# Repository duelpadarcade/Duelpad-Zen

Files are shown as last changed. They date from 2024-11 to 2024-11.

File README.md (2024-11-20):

## **Duelpad Zen**

Duelpad zen is a split-layout all-button controller, which is based on GP2040-CE projects. So it inherits the features, and is also added with something new.




## **Features**

- A navigating stick used with a humble UI,which can change the working status of the controller.
- Select from 13 input modes including X-Input, Nintendo Switch, Playstation 4/5, Xbox One, D-Input, and Keyboard
- Input latency average of 0.76ms in Xinput and 0.90ms for Playstation 5.
- Multiple SOCD cleaning modes - Up Priority (a.k.a. Stickless), Neutral, and Second Input Priority.
- Left and Right stick emulation via D-pad inputs as well as dedicated toggle switches.
- Dual direction via D-pad + LS/RS.
- Reversed input via a button.
- [Turbo and Turbo LED](https://gp2040-ce.info/add-ons/turbo) with selectable speed
- Per-button RGB LED support.
- PWM Player indicator LED support (XInput only).
- Multiple LED profiles support.
- Support for 128x64 monochrome I2C displays - SSD1306, SH1106, and SH1107 compatible.
- Custom startup splash screen and easy image upload via web configuration.
- Support for passive buzzer speaker (3v or 5v).
- [Built-in, embedded web configuration](https://gp2040-ce.info/web-configurator) - No download required!
- A bunch of RGB lights run by an extra MCU

## Support

We welcome anyone with ideas or issues to join us:

Official Website: www.duelpad.com

Discord Server:[DUELPAD](https://discord.gg/BXeWntUJ8B)

## Acknowledgements

This project is based on the excellent work of GP2040-CE team([Contributors to OpenStickCommunity/GP2040-CE · GitHub](https://github.com/OpenStickCommunity/GP2040-CE/graphs/contributors))

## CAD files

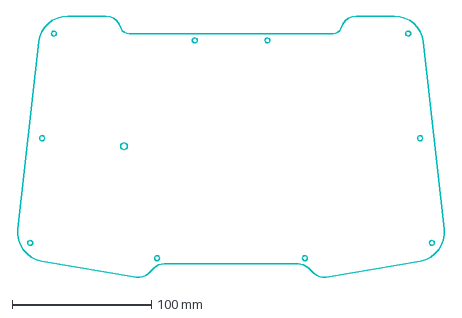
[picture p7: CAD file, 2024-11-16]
laser cut/Zen16-top4.dxf
308.3 x 187.8 mm

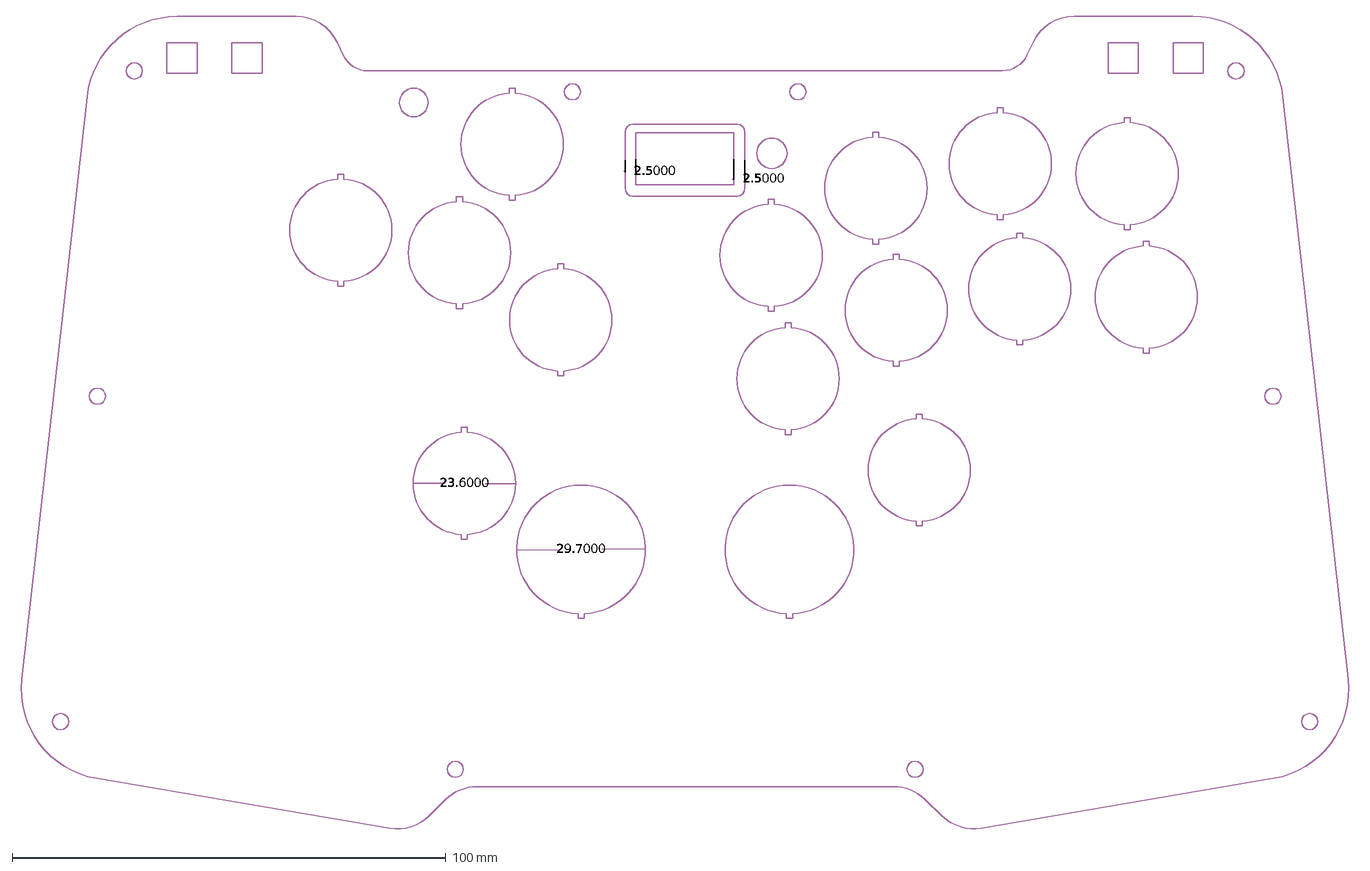
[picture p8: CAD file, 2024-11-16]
laser cut/Zen16-top1-balck.dxf
23.6000
29.7000
2.5000

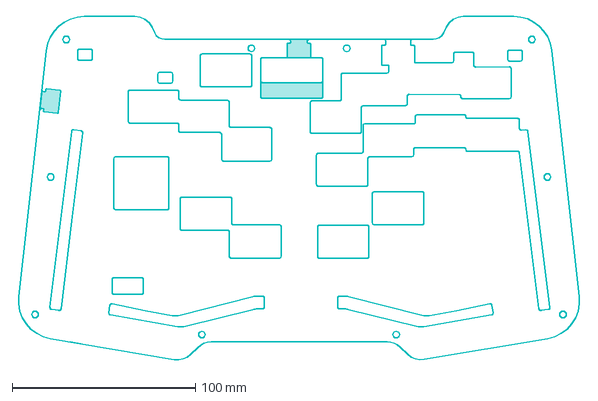
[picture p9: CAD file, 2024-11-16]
laser cut/Zen16-top3.dxf
308.3 x 187.8 mm

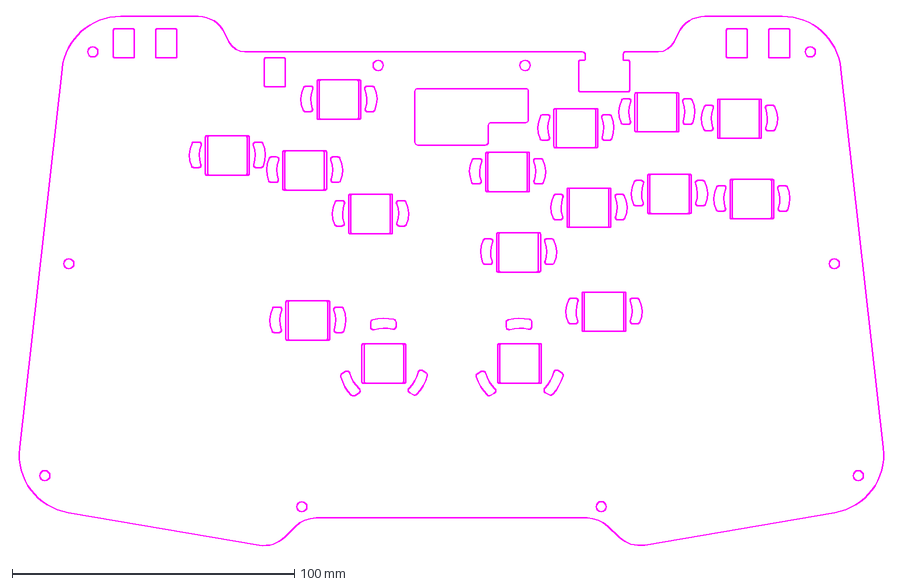
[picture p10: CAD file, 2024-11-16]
laser cut/Zen16-top2.dxf
308.3 x 187.8 mm

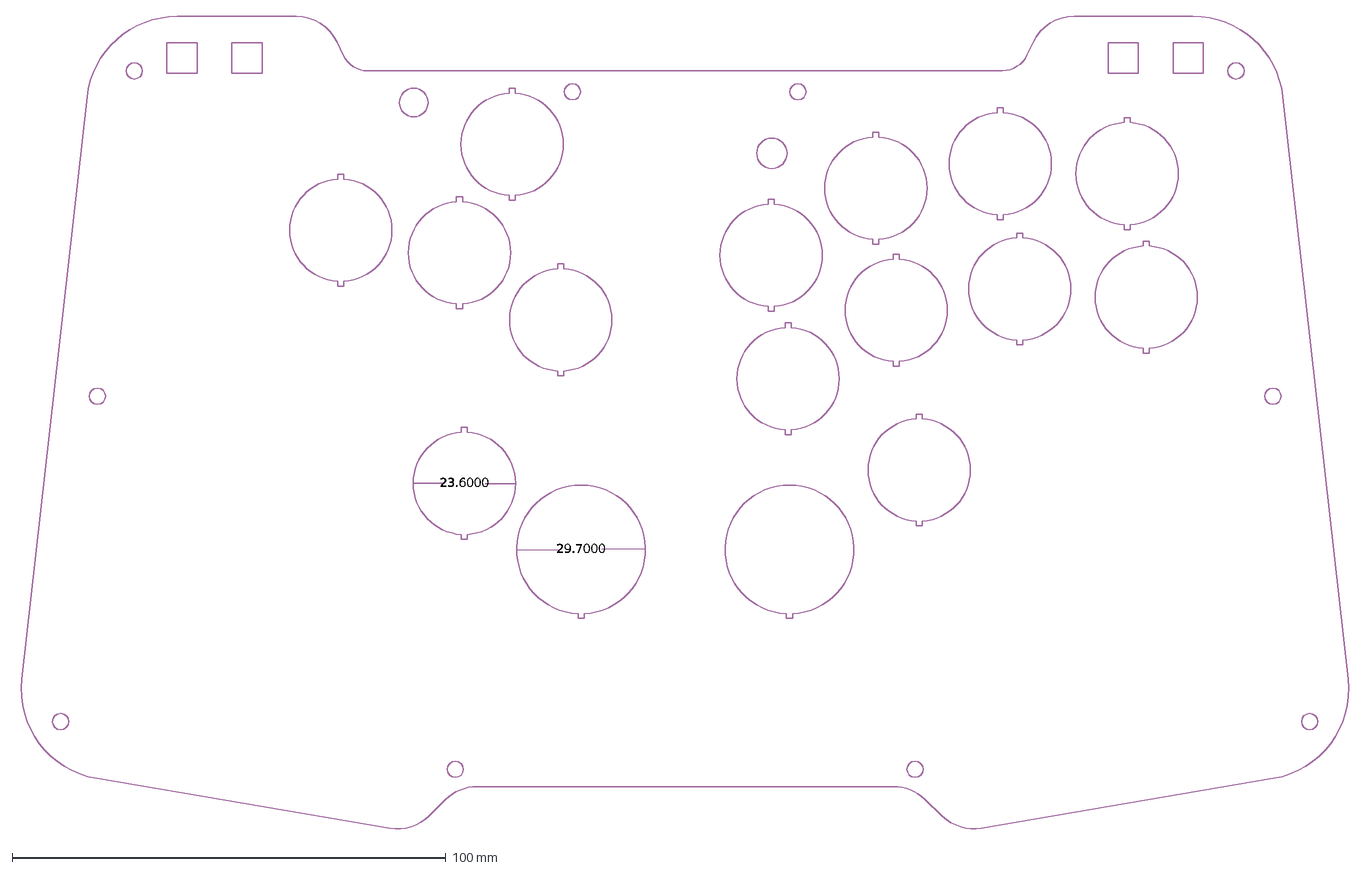
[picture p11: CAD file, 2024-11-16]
laser cut/Zen16-top1-crystal.dxf
23.6000
29.7000

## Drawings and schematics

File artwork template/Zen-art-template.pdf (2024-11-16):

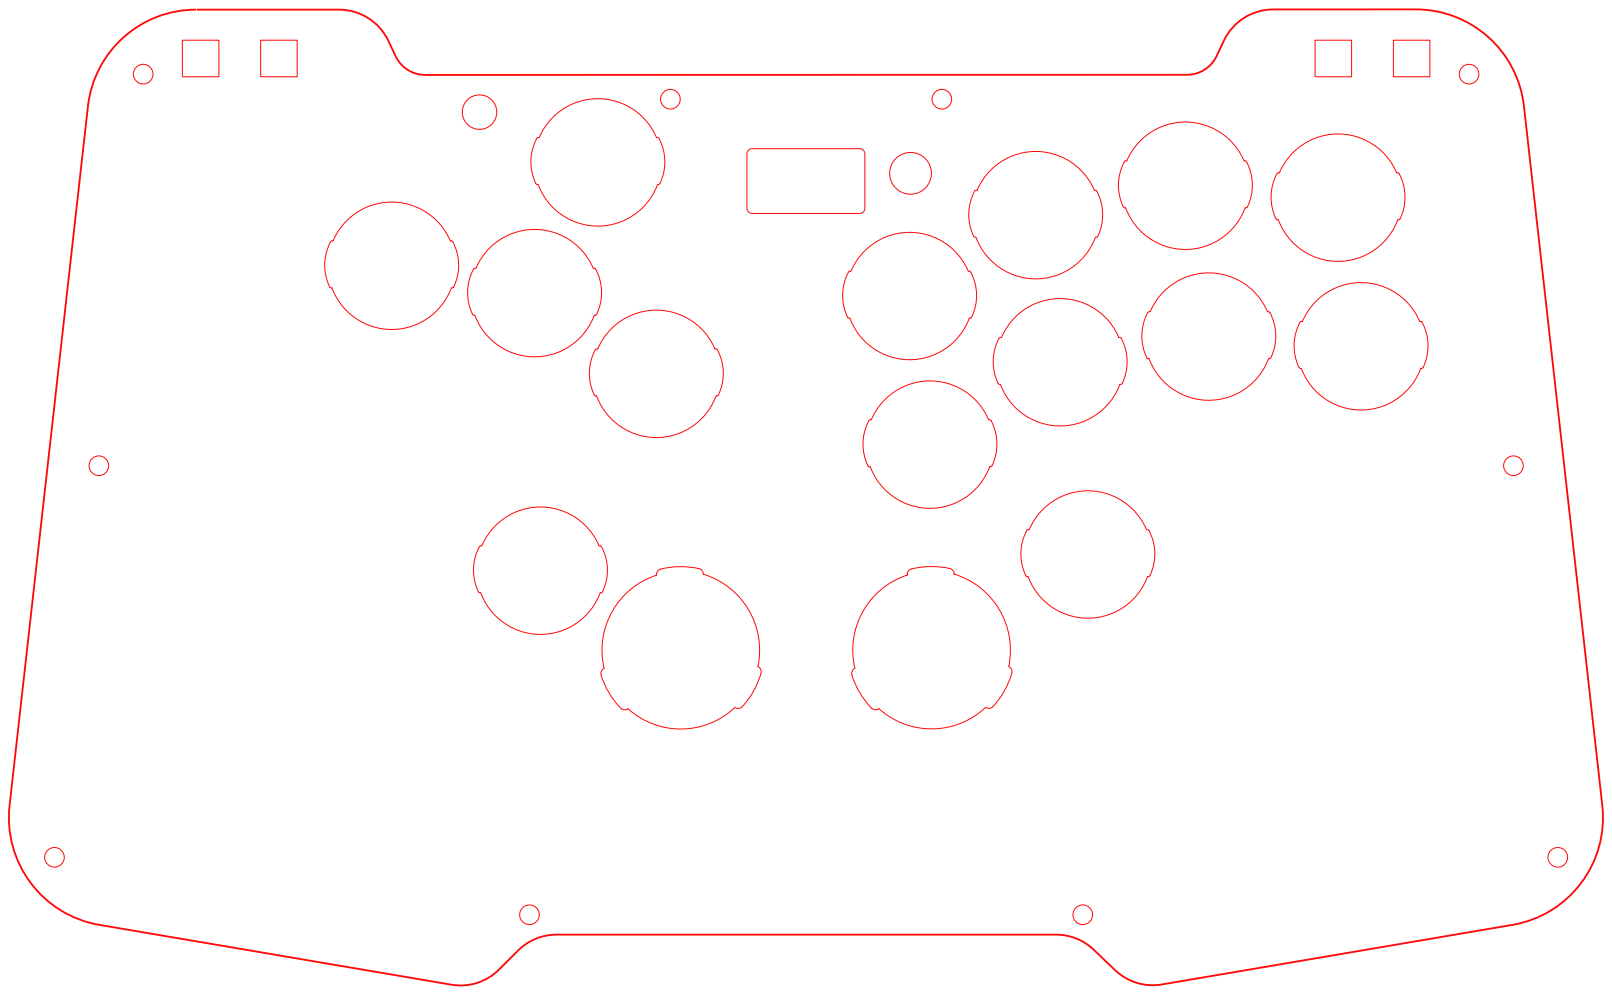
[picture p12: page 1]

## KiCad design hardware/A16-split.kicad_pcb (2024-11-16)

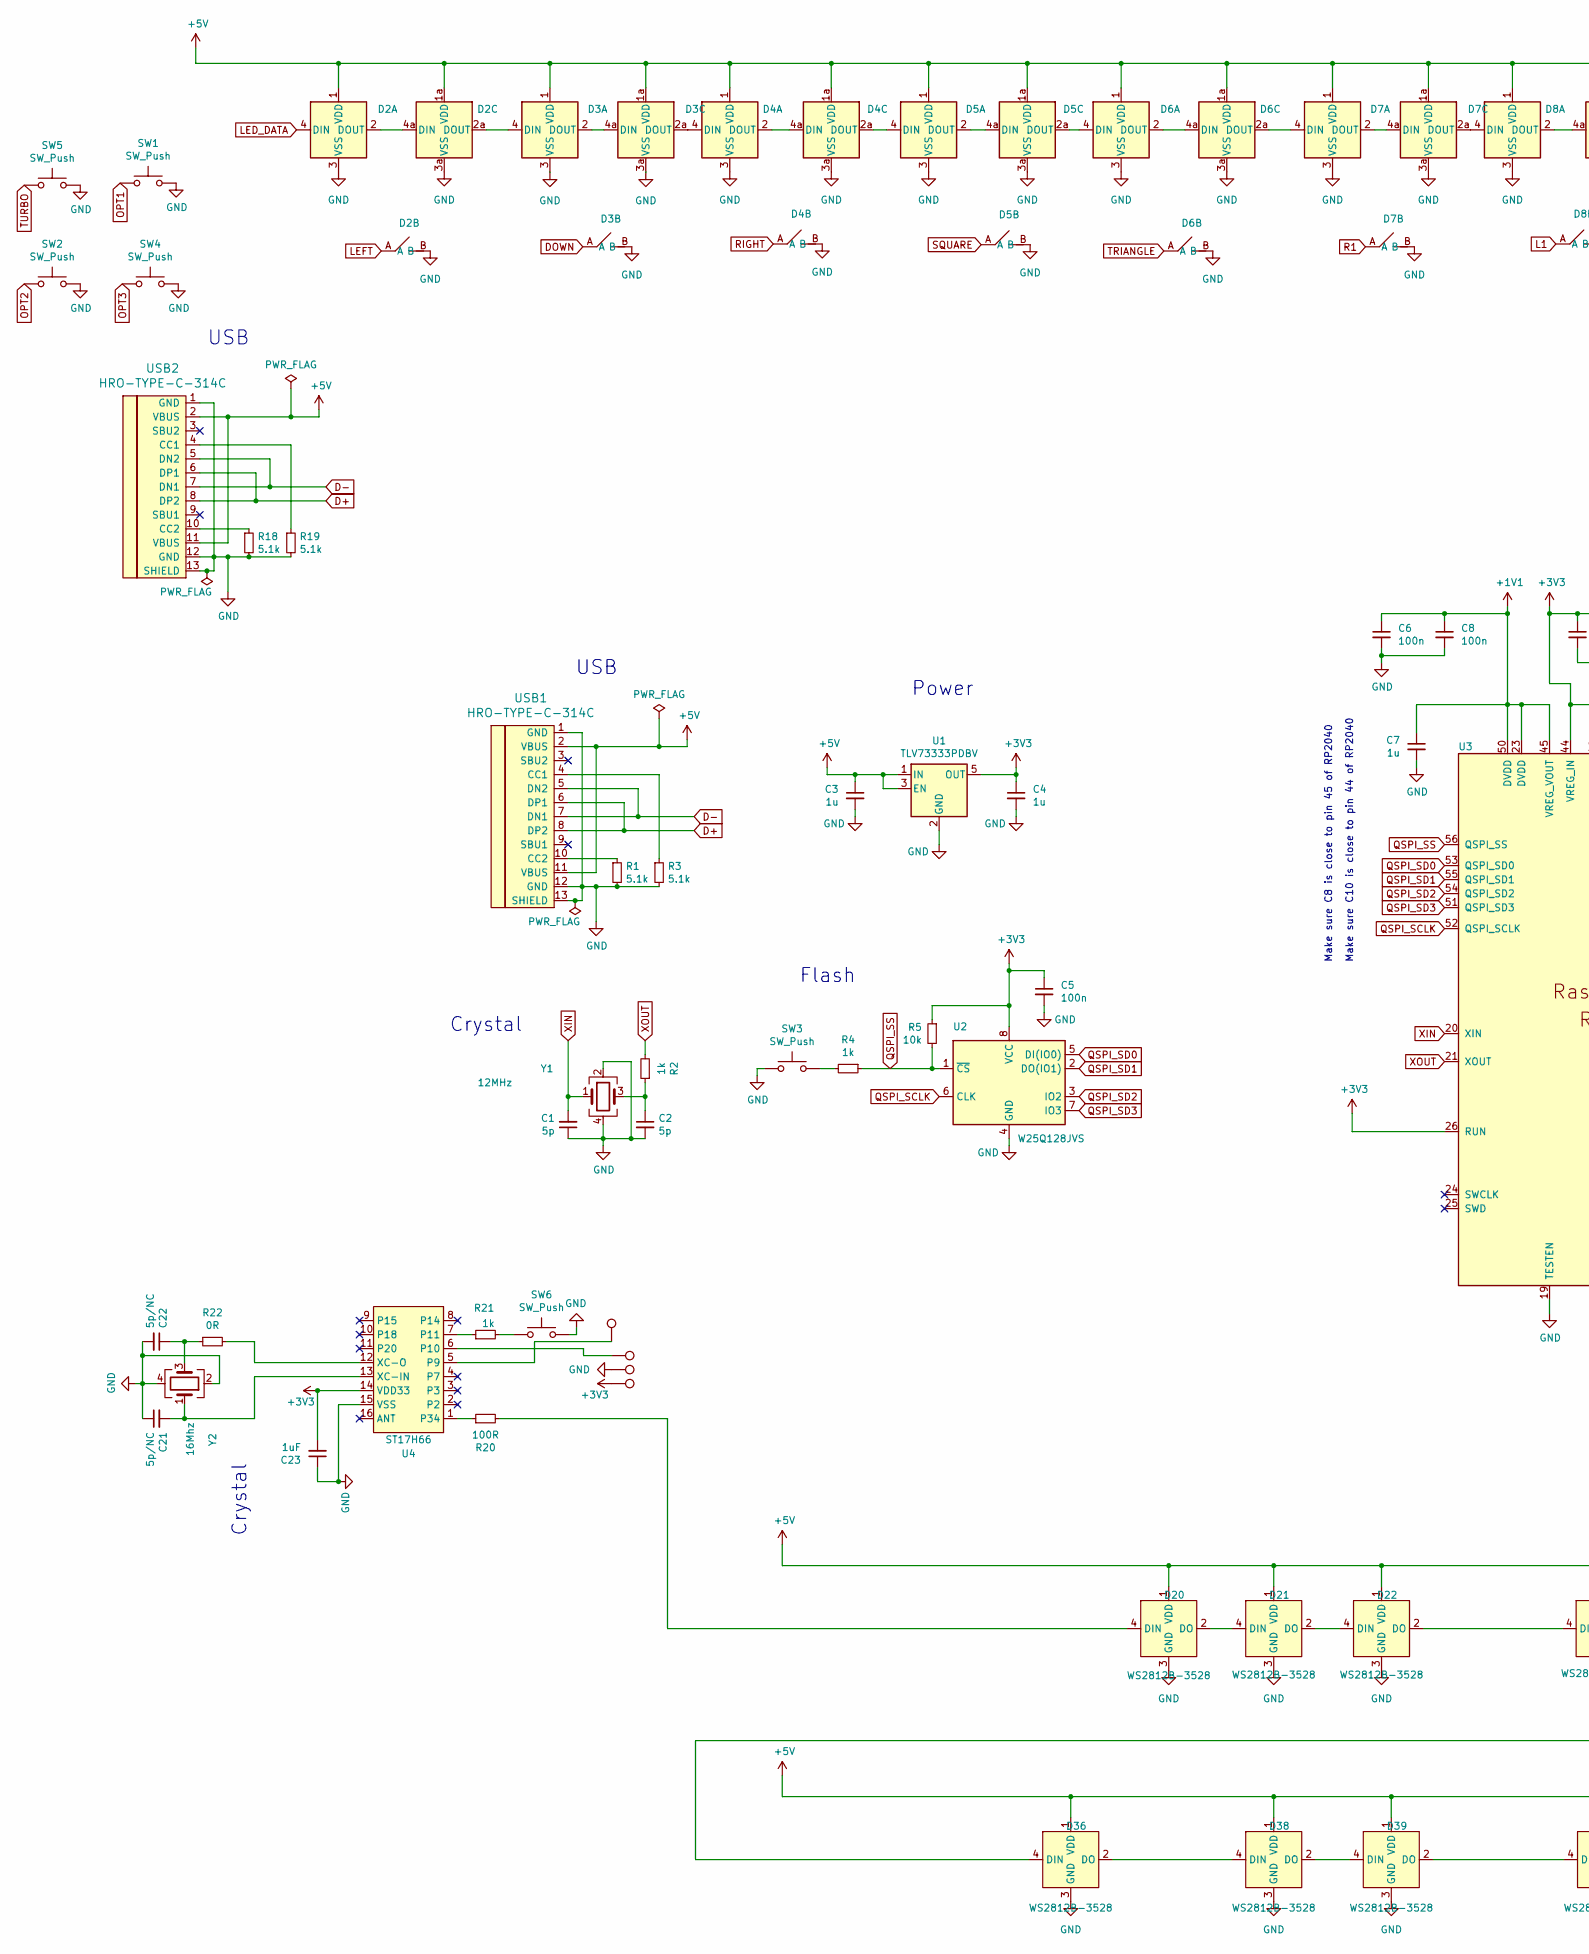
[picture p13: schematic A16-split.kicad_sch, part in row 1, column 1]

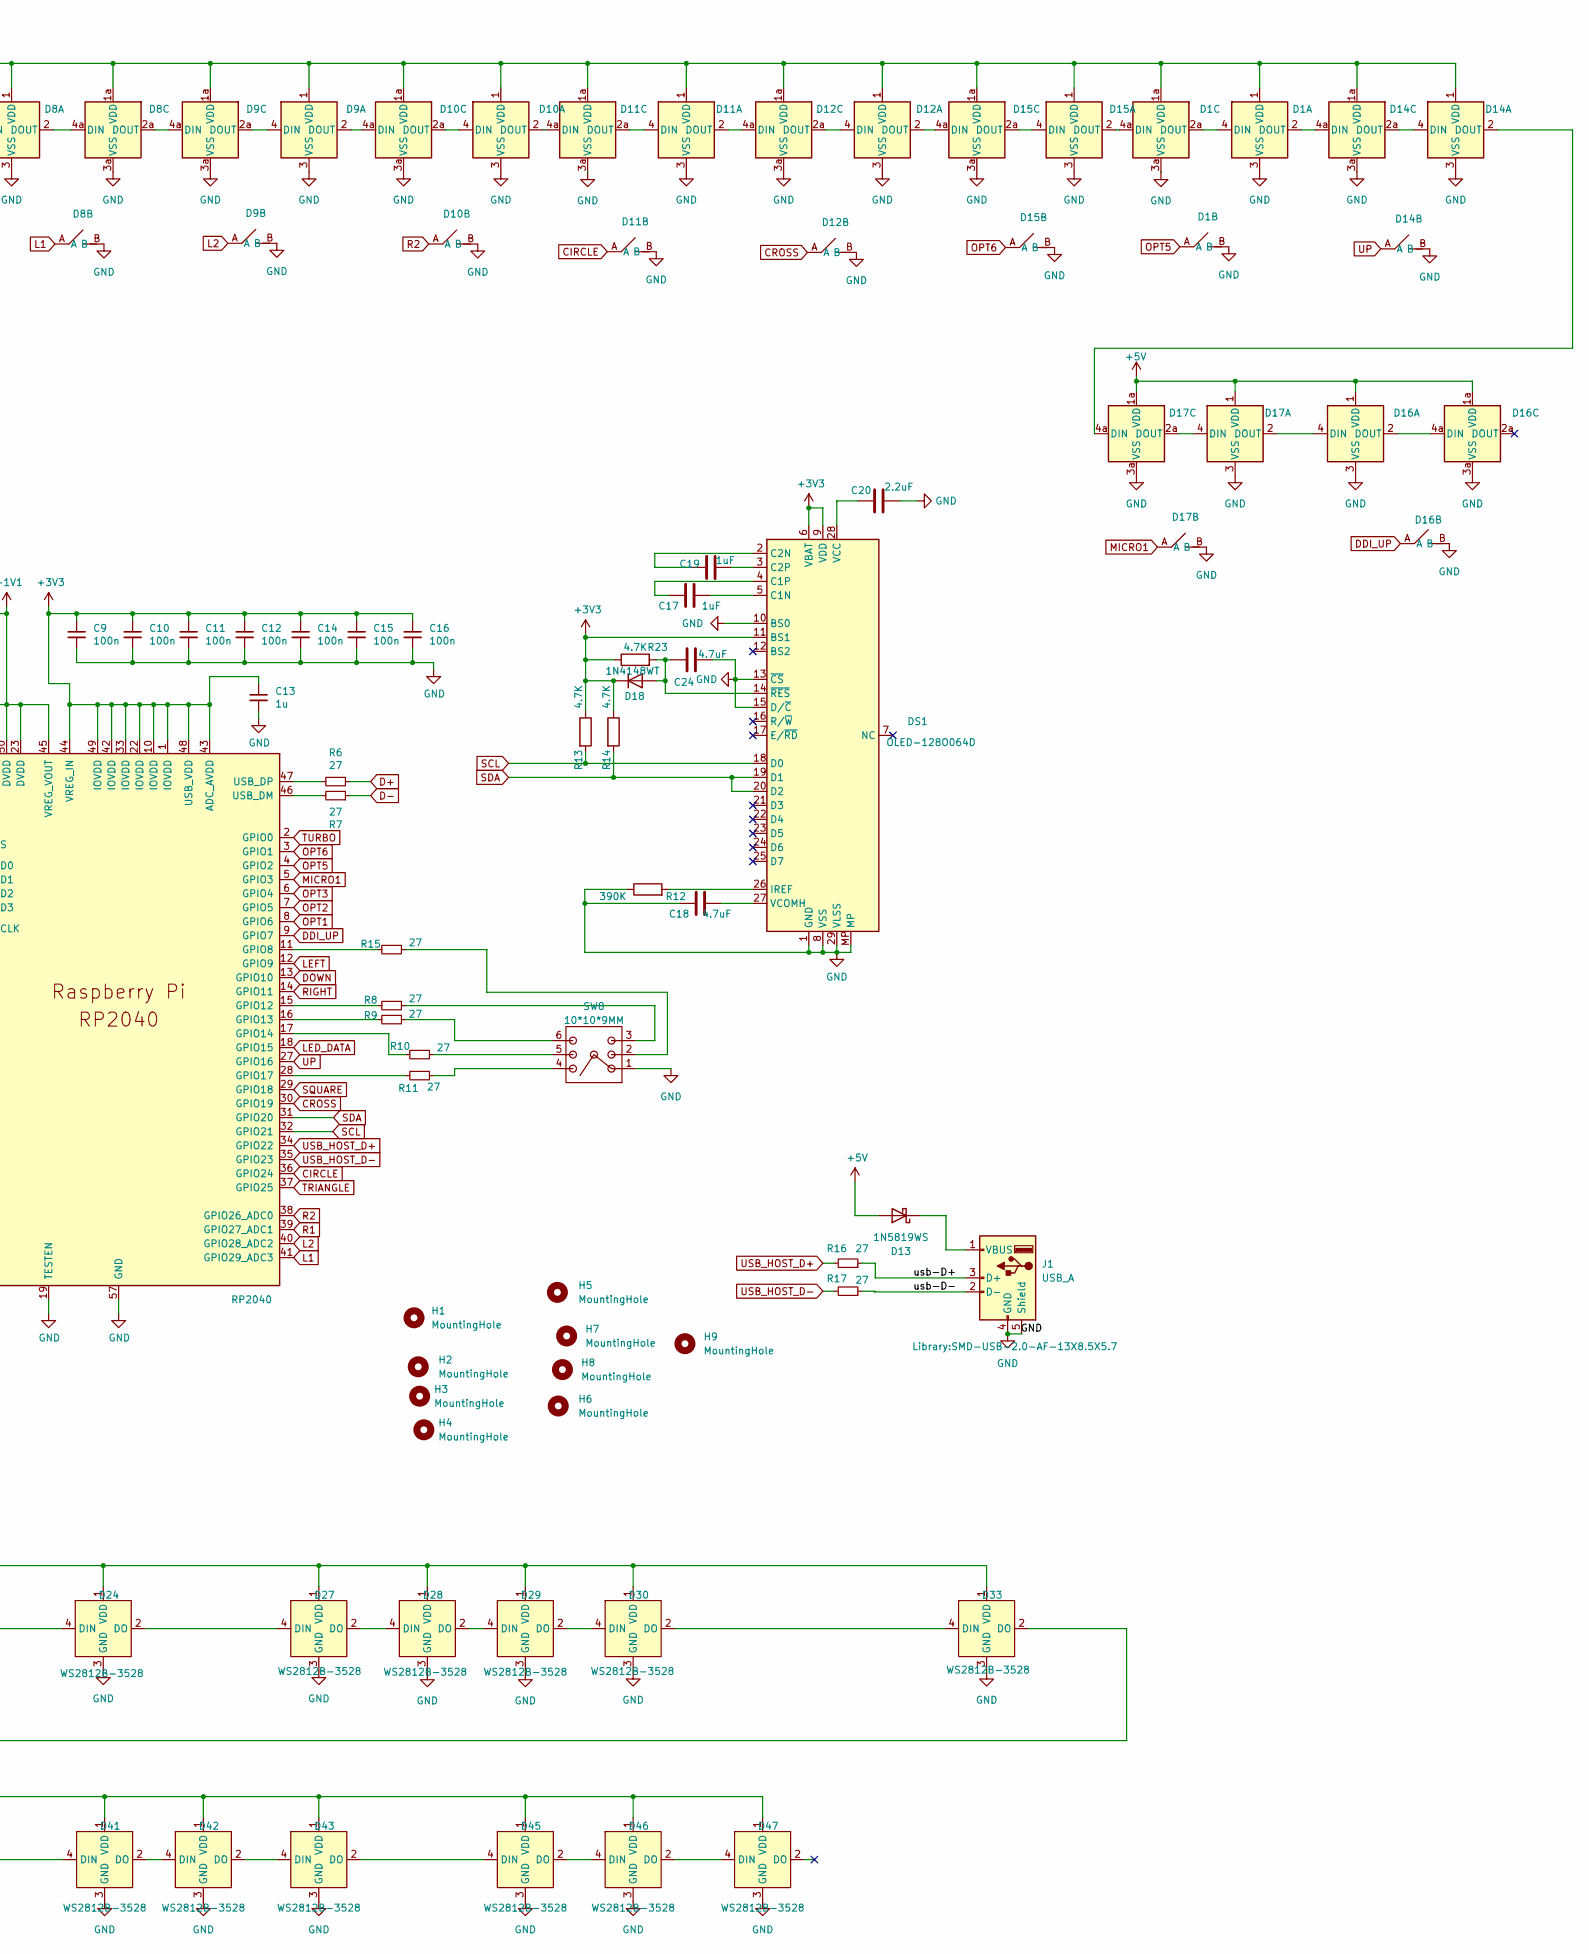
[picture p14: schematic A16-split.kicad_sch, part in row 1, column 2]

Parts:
C1, C2: 5p; C_0402_1005Metric; LCSC C1570
C3, C4, C7, C13: 1u; C_0402_1005Metric; LCSC C52923
C5, C6, C8, C9, C10, C11, C12, C14, C15, C16: 100n; C_0402_1005Metric; LCSC C1525
C17, C19: 1uF; C_0402_1005Metric
C18, C24: 4.7uF; C_0603_1608Metric
C20: 2.2uF; C_0603_1608Metric
C21, C22: 5p/NC; C_0402_1005Metric; LCSC C1570
C23: 1uF; C_0402_1005Metric; LCSC C52923
D1, D2, D3, D4, D5, D6, D7, D8, D9, D10, D11, D12, D14, D15, D16, D17: GATERON_KB_HOTSWAP_WS2812B; gateron_Kailh_PG1353_2LED-5.1MM
D13: 1N5819WS; D_SOD-323
D18: 1N4148WT; D_SOD-523
D20, D21, D22, D24, D27, D28, D29, D30, D33, D36, D38, D39, D41, D42, D43, D45, D46, D47: WS2812B-3528; SMD-LED-WS2812B-3528
DS1: OLED-128O064D; Flatbox_OLED_096-1
H1, H2, H3, H4, H5, H6, H7, H8, H9: MountingHole; MountingHole_3.15mm_M6
J1: USB_A; SMD-USB-2.0-AF-13X8.5X5.7
R1, R3, R18, R19: 5.1k; R_0402_1005Metric; LCSC C25905
R2, R4, R21: 1k; R_0402_1005Metric; LCSC C11702
R5: 10k; R_0402_1005Metric; LCSC C25744
R6, R7, R8, R9, R10, R11, R15, R16, R17: 27; R_0402_1005Metric; LCSC C138021
R12: 390K; R_0402_1005Metric
R13, R14, R23: 4.7K; R_0402_1005Metric
R20: 100R; R_0402_1005Metric; LCSC C11702
R22: 0R; R_0402_1005Metric; LCSC C11702
SW1, SW2, SW4, SW5: SW_Push; SW_Push_1P1T_NO_6x6mm_H5mm
SW3, SW6: SW_Push; SW_Push_1P1T_NO_6x6mm_H5mm; LCSC C271750
SW8: 10*10*9MM; TSX103G901-10x10
TP1, TP2, TP3, TP4: TestPoint; TestPoint_Pad_D1.5mm
U1: TLV73333PDBV; SOT-23-5; LCSC C134139
U2: W25Q128JVS; SOIC-8_5.23x5.23mm_P1.27mm; LCSC C97521
U3: RP2040; RP2040-QFN-56; LCSC C2040
U4: ST17H66; TSSOP-16_4.4x5mm_P0.65mm
USB1, USB2: HRO-TYPE-C-314C; HRO-TYPE-MC-314C-4P16; LCSC C165948
Y1: 12MHz; Crystal_SMD_3225-4Pin_3.2x2.5mm; LCSC C9002
Y2: 16Mhz; Crystal_SMD_3225-4Pin_3.2x2.5mm; LCSC C9002

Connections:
+1V1: C6.1, C7.1, C8.1, U3.23 (DVDD), U3.45 (VREG_VOUT), U3.50 (DVDD)
+3V3: C4.1, C5.1, C9.1, C10.1, C11.1, C12.1, C13.1, C14.1, C15.1, C16.1, C23.2, D18.1 (K), DS1.6 (VBAT), DS1.9 (VDD), DS1.11 (BS1), R5.1, R13.1, R14.1, R23.1, TP4.1, U1.5 (OUT), U2.8 (VCC), U3.1 (IOVDD), U3.10 (IOVDD), U3.22 (IOVDD), U3.26 (RUN), U3.33 (IOVDD), U3.42 (IOVDD), U3.43 (ADC_AVDD), U3.44 (VREG_IN), U3.48 (USB_VDD), U3.49 (IOVDD), U4.14 (VDD33)
+5V: C3.1, D1.1 (VDD), D1.1a (VDD), D2.1 (VDD), D2.1a (VDD), D3.1 (VDD), D3.1a (VDD), D4.1 (VDD), D4.1a (VDD), D5.1 (VDD), D5.1a (VDD), D6.1 (VDD), D6.1a (VDD), D7.1 (VDD), D7.1a (VDD), D8.1 (VDD), D8.1a (VDD), D9.1 (VDD), D9.1a (VDD), D10.1 (VDD), D10.1a (VDD), D11.1 (VDD), D11.1a (VDD), D12.1 (VDD), D12.1a (VDD), D13.2 (A), D14.1 (VDD), D14.1a (VDD), D15.1 (VDD), D15.1a (VDD), D16.1 (VDD), D16.1a (VDD), D17.1 (VDD), D17.1a (VDD), D20.1 (VDD), D21.1 (VDD), D22.1 (VDD), D24.1 (VDD), D27.1 (VDD), D28.1 (VDD), D29.1 (VDD), D30.1 (VDD), D33.1 (VDD), D36.1 (VDD), D38.1 (VDD), D39.1 (VDD), D41.1 (VDD), D42.1 (VDD), D43.1 (VDD), D45.1 (VDD), D46.1 (VDD), D47.1 (VDD), U1.1 (IN), U1.3 (EN), USB1.2 (VBUS), USB1.11 (VBUS), USB2.2 (VBUS), USB2.11 (VBUS)
/usb-D+: J1.3 (D+), R16.1
/usb-D-: J1.2 (D-), R17.1
CIRCLE: D11.A, U3.36 (GPIO24)
CROSS: D12.A, U3.30 (GPIO19)
D+: R6.1, USB1.6 (DP1), USB1.8 (DP2), USB2.6 (DP1), USB2.8 (DP2)
D-: R7.1, USB1.5 (DN2), USB1.7 (DN1), USB2.5 (DN2), USB2.7 (DN1)
DDI_UP: D16.A, U3.9 (GPIO7)
DOWN: D3.A, U3.13 (GPIO10)
GND: C1.1, C2.2, C3.2, C4.2, C5.2, C6.2, C7.2, C8.2, C9.2, C10.2, C11.2, C12.2, C13.2, C14.2, C15.2, C16.2, C18.1, C20.2, C21.1, C22.2, C23.1, C24.2, D1.3 (VSS), D1.3a (VSS), D1.B, D2.3 (VSS), D2.3a (VSS), D2.B, D3.3 (VSS), D3.3a (VSS), D3.B, D4.3 (VSS), D4.3a (VSS), D4.B, D5.3 (VSS), D5.3a (VSS), D5.B, D6.3 (VSS), D6.3a (VSS), D6.B, D7.3 (VSS), D7.3a (VSS), D7.B, D8.3 (VSS), D8.3a (VSS), D8.B, D9.3 (VSS), D9.3a (VSS), D9.B, D10.3 (VSS), D10.3a (VSS), D10.B, D11.3 (VSS), D11.3a (VSS), D11.B, D12.3 (VSS), D12.3a (VSS), D12.B, D14.3 (VSS), D14.3a (VSS), D14.B, D15.3 (VSS), D15.3a (VSS), D15.B, D16.3 (VSS), D16.3a (VSS), D16.B, D17.3 (VSS), D17.3a (VSS), D17.B, D20.3 (GND), D21.3 (GND), D22.3 (GND), D24.3 (GND), D27.3 (GND), D28.3 (GND), D29.3 (GND), D30.3 (GND), D33.3 (GND), D36.3 (GND), D38.3 (GND), D39.3 (GND), D41.3 (GND), D42.3 (GND), D43.3 (GND), D45.3 (GND), D46.3 (GND), D47.3 (GND), DS1.1 (GND), DS1.8 (VSS), DS1.10 (BS0), DS1.13 (~CS), DS1.15 (D/~C), DS1.29 (VLSS), DS1.30 (GND), DS1.MP, J1.4 (GND), J1.5 (Shield), R1.2, R3.2, R12.1, R18.2, R19.2, SW1.2, SW2.2, SW3.1, SW4.2, SW5.2, SW6.2, SW8.1, TP3.1, U1.2 (GND), U2.4 (GND), U3.19 (TESTEN), U3.57 (GND), U4.15 (VSS), USB1.1 (GND), USB1.12 (GND), USB1.13 (SHIELD), USB2.1 (GND), USB2.12 (GND), USB2.13 (SHIELD), Y1.2, Y1.4, Y2.2, Y2.4
L1: D8.A, U3.41 (GPIO29_ADC3)
L2: D9.A, U3.40 (GPIO28_ADC2)
LED_DATA: D2.4 (DIN), U3.18 (GPIO15)
LEFT: D2.A, U3.12 (GPIO9)
MICRO1: D17.A, U3.5 (GPIO3)
unnamed: C2.1, R2.1, Y1.3
unnamed: C22.1, R22.1, Y2.3
unnamed: D1.2a (DOUT), D1.4 (DIN)
unnamed: D2.2 (DOUT), D2.4a (DIN)
unnamed: D2.2a (DOUT), D3.4 (DIN)
unnamed: D3.2 (DOUT), D3.4a (DIN)
unnamed: D3.2a (DOUT), D4.4 (DIN)
unnamed: D4.2 (DOUT), D4.4a (DIN)
unnamed: D4.2a (DOUT), D5.4 (DIN)
unnamed: D5.2 (DOUT), D5.4a (DIN)
unnamed: D5.2a (DOUT), D6.4 (DIN)
unnamed: D6.2 (DOUT), D6.4a (DIN)
unnamed: D6.2a (DOUT), D7.4 (DIN)
unnamed: D7.2 (DOUT), D7.4a (DIN)
unnamed: D7.2a (DOUT), D8.4 (DIN)
unnamed: D8.2 (DOUT), D8.4a (DIN)
unnamed: D8.2a (DOUT), D9.4a (DIN)
unnamed: D9.2a (DOUT), D9.4 (DIN)
unnamed: D10.2a (DOUT), D10.4 (DIN)
unnamed: D10.2 (DOUT), D11.4a (DIN)
unnamed: D9.2 (DOUT), D10.4a (DIN)
unnamed: D11.2a (DOUT), D11.4 (DIN)
unnamed: D11.2 (DOUT), D12.4a (DIN)
unnamed: D12.2a (DOUT), D12.4 (DIN)
unnamed: D12.2 (DOUT), D15.4a (DIN)
unnamed: D13.1 (K), J1.1 (VBUS)
unnamed: D14.2a (DOUT), D14.4 (DIN)
unnamed: D14.2 (DOUT), D17.4a (DIN)
unnamed: D1.2 (DOUT), D14.4a (DIN)
unnamed: D15.2a (DOUT), D15.4 (DIN)
unnamed: D1.4a (DIN), D15.2 (DOUT)
unnamed: D16.4 (DIN), D17.2 (DOUT)
unnamed: D16.2 (DOUT), D16.4a (DIN)
unnamed: D17.2a (DOUT), D17.4 (DIN)
unnamed: C24.1, D18.2 (A), DS1.14 (~RES), R23.2
unnamed: D20.4 (DIN), R20.2
unnamed: D20.2 (DO), D21.4 (DIN)
unnamed: D21.2 (DO), D22.4 (DIN)
unnamed: D22.2 (DO), D24.4 (DIN)
unnamed: D24.2 (DO), D27.4 (DIN)
unnamed: D27.2 (DO), D28.4 (DIN)
unnamed: D28.2 (DO), D29.4 (DIN)
unnamed: D29.2 (DO), D30.4 (DIN)
unnamed: D30.2 (DO), D33.4 (DIN)
unnamed: D33.2 (DO), D36.4 (DIN)
unnamed: D36.2 (DO), D38.4 (DIN)
unnamed: D38.2 (DO), D39.4 (DIN)
unnamed: D39.2 (DO), D41.4 (DIN)
unnamed: D41.2 (DO), D42.4 (DIN)
unnamed: D42.2 (DO), D43.4 (DIN)
unnamed: D43.2 (DO), D45.4 (DIN)
unnamed: D45.2 (DO), D46.4 (DIN)
unnamed: D46.2 (DO), D47.4 (DIN)
unnamed: C17.2, DS1.5 (C1N)
unnamed: C17.1, DS1.4 (C1P)
unnamed: C19.1, DS1.2 (C2N)
unnamed: C19.2, DS1.3 (C2P)
unnamed: DS1.26 (IREF), R12.2
unnamed: C20.1, DS1.28 (VCC)
unnamed: C18.2, DS1.27 (VCOMH)
unnamed: R4.2, SW3.2
unnamed: R8.1, SW8.3
unnamed: R9.1, SW8.6
unnamed: R10.1, SW8.5
unnamed: R11.1, SW8.4
unnamed: R15.1, SW8.2
unnamed: R21.2, SW6.1
unnamed: R15.2, U3.11 (GPIO8)
unnamed: R8.2, U3.15 (GPIO12)
unnamed: R9.2, U3.16 (GPIO13)
unnamed: R10.2, U3.17 (GPIO14)
unnamed: R11.2, U3.28 (GPIO17)
unnamed: R7.2, U3.46 (USB_DM)
unnamed: R6.2, U3.47 (USB_DP)
unnamed: TP1.1, U4.5 (P9)
unnamed: TP2.1, U4.6 (P10)
unnamed: R21.1, U4.7 (P11)
unnamed: R20.1, U4.1 (P34)
unnamed: C21.2, U4.13 (XC-IN), Y2.1
unnamed: R22.2, U4.12 (XC-O)
unnamed: R3.1, USB1.4 (CC1)
unnamed: R1.1, USB1.10 (CC2)
unnamed: R19.1, USB2.4 (CC1)
unnamed: R18.1, USB2.10 (CC2)
OPT1: SW1.1, U3.8 (GPIO6)
OPT2: SW2.1, U3.7 (GPIO5)
OPT3: SW4.1, U3.6 (GPIO4)
OPT5: D1.A, U3.4 (GPIO2)
OPT6: D15.A, U3.3 (GPIO1)
QSPI_SCLK: U2.6 (CLK), U3.52 (QSPI_SCLK)
QSPI_SD0: U2.5 (DI(IO0)), U3.53 (QSPI_SD0)
QSPI_SD1: U2.2 (DO(IO1)), U3.55 (QSPI_SD1)
QSPI_SD2: U2.3 (IO2), U3.54 (QSPI_SD2)
QSPI_SD3: U2.7 (IO3), U3.51 (QSPI_SD3)
QSPI_SS: R4.1, R5.2, U2.1 (~CS), U3.56 (QSPI_SS)
R1: D7.A, U3.39 (GPIO27_ADC1)
R2: D10.A, U3.38 (GPIO26_ADC0)
RIGHT: D4.A, U3.14 (GPIO11)
SCL: DS1.18 (D0), R13.2, U3.32 (GPIO21)
SDA: DS1.19 (D1), DS1.20 (D2), R14.2, U3.31 (GPIO20)
SQUARE: D5.A, U3.29 (GPIO18)
TRIANGLE: D6.A, U3.37 (GPIO25)
TURBO: SW5.1, U3.2 (GPIO0)
UP: D14.A, U3.27 (GPIO16)
USB_HOST_D+: R16.2, U3.34 (GPIO22)
USB_HOST_D-: R17.2, U3.35 (GPIO23)
XIN: C1.2, U3.20 (XIN), Y1.1
XOUT: R2.2, U3.21 (XOUT)

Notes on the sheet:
USB
Make sure C10 is close to pin 44 of RP2040
Crystal
Flash
Power
Make sure C8 is close to pin 45 of RP2040

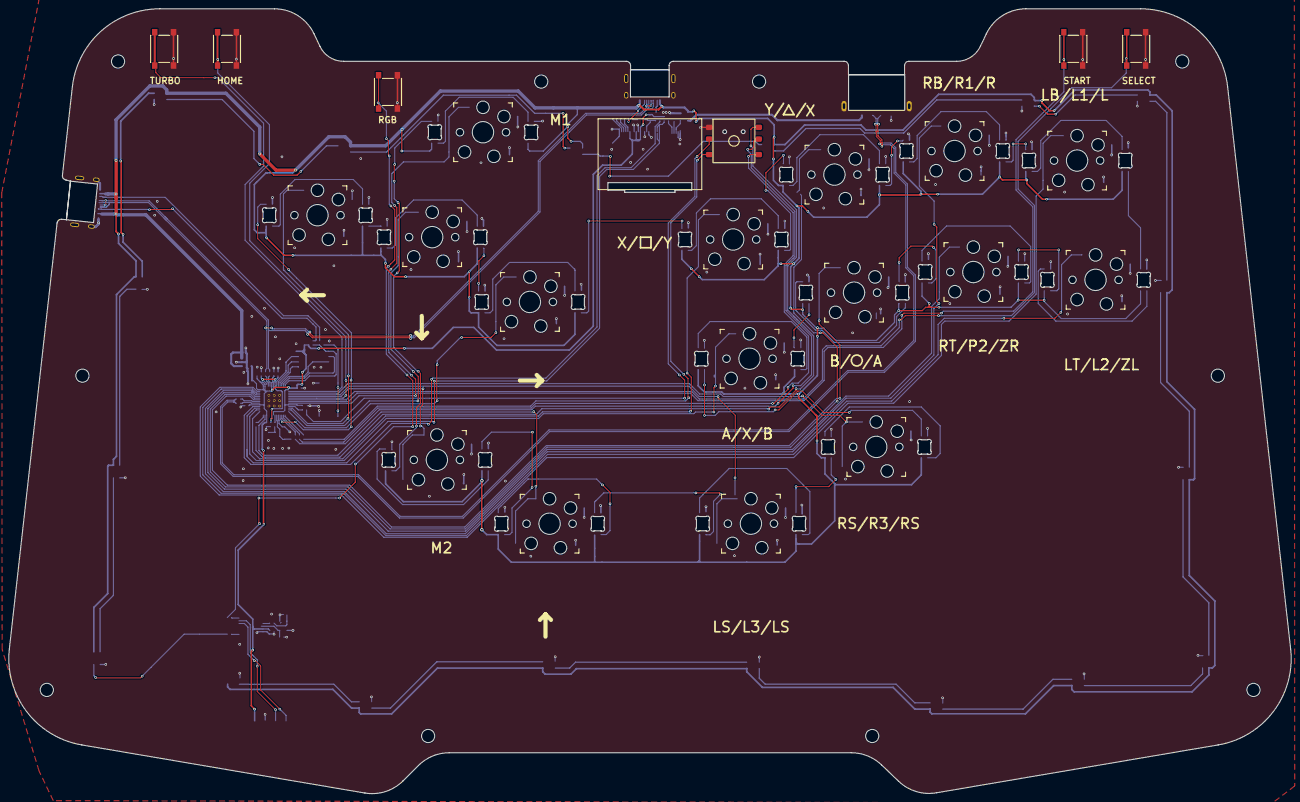
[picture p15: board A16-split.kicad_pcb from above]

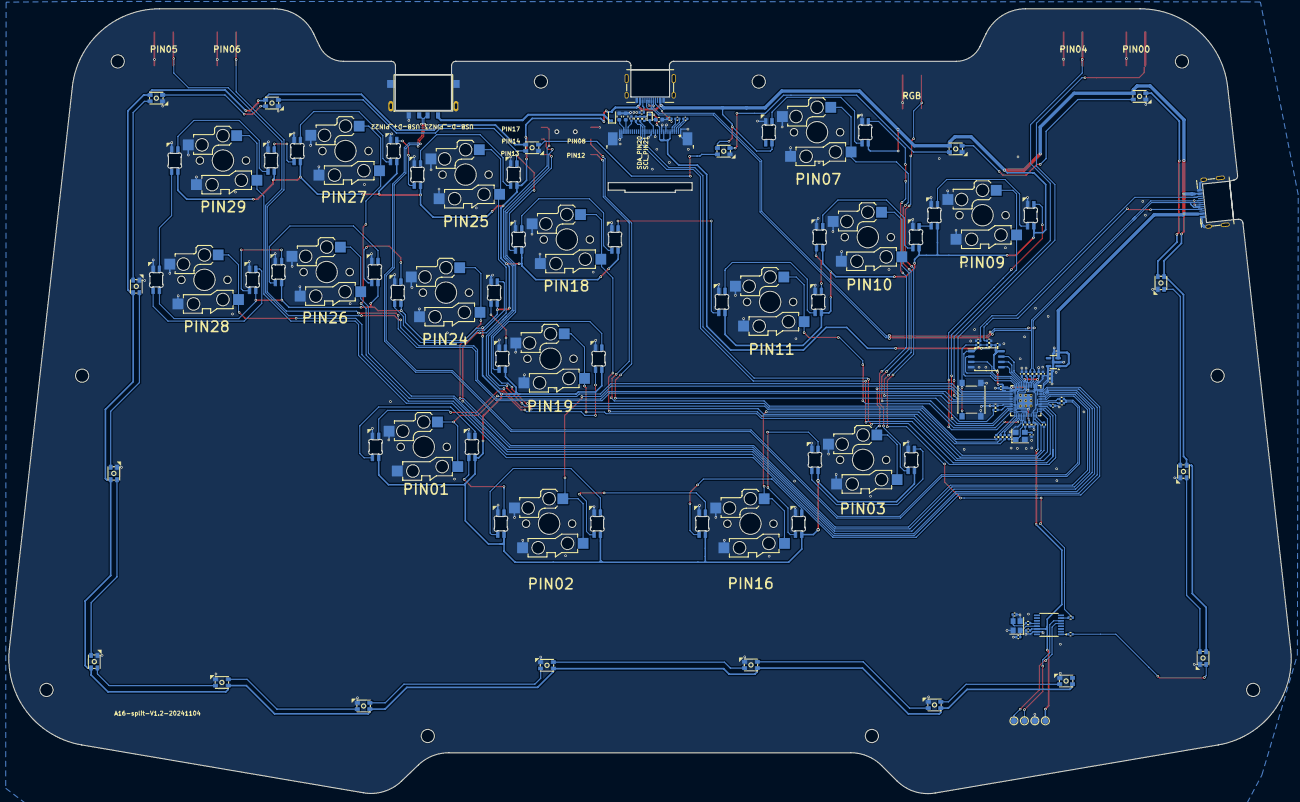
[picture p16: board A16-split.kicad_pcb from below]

Board: 2 copper layers, 306.1 x 187.3 mm, 114 parts (81 on the bottom side), 125 nets.

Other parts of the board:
H9#2: MountingHole; MountingHole_3.15mm_M6

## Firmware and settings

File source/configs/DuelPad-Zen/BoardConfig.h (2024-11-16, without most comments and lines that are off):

#define EPIG_A16_CONFIG_H_
#include "enums.pb.h"
#include "class/hid/hid.h"
#define BOARD_CONFIG_LABEL "DuelPad-Zen"
#define GPIO_PIN_16 GpioAction::BUTTON_PRESS_UP     // UP     | UP     | UP      | UP       | UP     | UP     |
#define GPIO_PIN_10 GpioAction::BUTTON_PRESS_DOWN   // DOWN   | DOWN   | DOWN    | DOWN     | DOWN   | DOWN   |
#define GPIO_PIN_11 GpioAction::BUTTON_PRESS_RIGHT  // RIGHT  | RIGHT  | RIGHT   | RIGHT    | RIGHT  | RIGHT  |
#define GPIO_PIN_09 GpioAction::BUTTON_PRESS_LEFT   // LEFT   | LEFT   | LEFT    | LEFT     | LEFT   | LEFT   |
#define GPIO_PIN_19 GpioAction::BUTTON_PRESS_B1     // B1     | A      | B       | Cross    | 2      | K1     |
#define GPIO_PIN_24 GpioAction::BUTTON_PRESS_B2     // B2     | B      | A       | Circle   | 3      | K2     |
#define GPIO_PIN_26 GpioAction::BUTTON_PRESS_R2     // R2     | RT     | ZR      | R2       | 8      | K3     |
#define GPIO_PIN_28 GpioAction::BUTTON_PRESS_L2     // L2     | LT     | ZL      | L2       | 7      | K4     |
#define GPIO_PIN_18 GpioAction::BUTTON_PRESS_B3     // B3     | X      | Y       | Square   | 1      | P1     |
#define GPIO_PIN_25 GpioAction::BUTTON_PRESS_B4     // B4     | Y      | X       | Triangle | 4      | P2     |
#define GPIO_PIN_27 GpioAction::BUTTON_PRESS_R1     // R1     | RB     | R       | R1       | 6      | P3     |
#define GPIO_PIN_29 GpioAction::BUTTON_PRESS_L1     // L1     | LB     | L       | L1       | 5      | P4     |
#define GPIO_PIN_05 GpioAction::BUTTON_PRESS_S1     // S1     | Back   | Minus   | Select   | 9      | Coin   |
#define GPIO_PIN_06 GpioAction::BUTTON_PRESS_S2     // S2     | Start  | Plus    | Start    | 10     | Start  |
#define GPIO_PIN_02 GpioAction::BUTTON_PRESS_L3     // L3     | LS     | LS      | L3       | 11     | LS     |
#define GPIO_PIN_01 GpioAction::BUTTON_PRESS_R3     // R3     | RS     | RS      | R3       | 12     | RS     |
#define GPIO_PIN_04 GpioAction::BUTTON_PRESS_A1     // A1     | Guide  | Home    | PS       | 13     | ~      |
#define GPIO_PIN_13 GpioAction::BUTTON_PRESS_E1     //
#define GPIO_PIN_17 GpioAction::BUTTON_PRESS_E2     //
#define GPIO_PIN_14 GpioAction::BUTTON_PRESS_E3     //press
#define GPIO_PIN_08 GpioAction::BUTTON_PRESS_E4     //left
#define GPIO_PIN_12 GpioAction::BUTTON_PRESS_E5     //right
#define GPIO_PIN_07 GpioAction::BUTTON_PRESS_UP
#define GPIO_PIN_03 GpioAction::BUTTON_PRESS_MACRO_2
#define KEY_DPAD_UP     HID_KEY_ARROW_UP      // UP     | UP     | UP      | UP       | UP     | UP     |
#define KEY_DPAD_DOWN   HID_KEY_ARROW_DOWN    // DOWN   | DOWN   | DOWN    | DOWN     | DOWN   | DOWN   |
#define KEY_DPAD_RIGHT  HID_KEY_ARROW_RIGHT   // RIGHT  | RIGHT  | RIGHT   | RIGHT    | RIGHT  | RIGHT  |
#define KEY_DPAD_LEFT   HID_KEY_ARROW_LEFT    // LEFT   | LEFT   | LEFT    | LEFT     | LEFT   | LEFT   |
#define KEY_BUTTON_B1   HID_KEY_SHIFT_LEFT    // B1     | A      | B       | Cross    | 2      | K1     |
#define KEY_BUTTON_B2   HID_KEY_Z             // B2     | B      | A       | Circle   | 3      | K2     |
#define KEY_BUTTON_R2   HID_KEY_X             // R2     | RT     | ZR      | R2       | 8      | K3     |
#define KEY_BUTTON_L2   HID_KEY_V             // L2     | LT     | ZL      | L2       | 7      | K4     |
#define KEY_BUTTON_B3   HID_KEY_CONTROL_LEFT  // B3     | X      | Y       | Square   | 1      | P1     |
#define KEY_BUTTON_B4   HID_KEY_ALT_LEFT      // B4     | Y      | X       | Triangle | 4      | P2     |
#define KEY_BUTTON_R1   HID_KEY_SPACE         // R1     | RB     | R       | R1       | 6      | P3     |
#define KEY_BUTTON_L1   HID_KEY_C             // L1     | LB     | L       | L1       | 5      | P4     |
#define KEY_BUTTON_S1   HID_KEY_5             // S1     | Back   | Minus   | Select   | 9      | Coin   |
#define KEY_BUTTON_S2   HID_KEY_1             // S2     | Start  | Plus    | Start    | 10     | Start  |
#define KEY_BUTTON_L3   HID_KEY_EQUAL         // L3     | LS     | LS      | L3       | 11     | LS     |
#define KEY_BUTTON_R3   HID_KEY_MINUS         // R3     | RS     | RS      | R3       | 12     | RS     |
#define KEY_BUTTON_A1   HID_KEY_9             // A1     | Guide  | Home    | PS       | 13     | ~      |
#define KEY_BUTTON_A2   HID_KEY_F2            // A2     | ~      | Capture | ~        | 14     | ~      |
#define KEY_BUTTON_FN   -1                    // Hotkey Function                                        |
#define GPIO_PIN_15 GpioAction::ASSIGNED_TO_ADDON
#define USB_PERIPHERAL_ENABLED 1
#define USB_PERIPHERAL_PIN_DPLUS 22
#define USB_PERIPHERAL_PIN_ORDER 0
#define TURBO_ENABLED 1
#define GPIO_PIN_00 GpioAction::BUTTON_PRESS_TURBO
#define DEFAULT_INPUT_MODE_R1 INPUT_MODE_XBONE
#define DEFAULT_INPUT_MODE_R2 INPUT_MODE_KEYBOARD
#define DEFAULT_INPUT_MODE_B4 INPUT_MODE_PS5
#define DEFAULT_INPUT_MODE_B3 INPUT_MODE_XINPUT
#define DEFAULT_INPUT_MODE_B2 INPUT_MODE_GENERIC
#define DEFAULT_INPUT_MODE_B1 INPUT_MODE_SWITCH
#define DEFAULT_INPUT_MODE_L2 INPUT_MODE_PS4
#define DEFAULT_PS5AUTHENTICATION_TYPE INPUT_MODE_AUTH_TYPE_USB
#define XBONEPASSTHROUGH_ENABLED 1
#define FOCUS_MODE_ENABLED 1
#define FOCUS_MODE_MACRO_LOCK_ENABLED 1
#define FOCUS_MODE_BUTTON_MASK GAMEPAD_MASK_S1 | GAMEPAD_MASK_S2 | GAMEPAD_MASK_A1 | GAMEPAD_MASK_A2 | GAMEPAD_MASK_L3 | GAMEPAD_MASK_R3
#define BOARD_LEDS_PIN 15
#define REVERSE_LED_PIN -1
#define LEDS_THEME_INDEX 20
#define LED_BRIGHTNESS_MAXIMUM 255
#define LED_BRIGHTNESS_STEPS 5
#define LEDS_BRIGHTNESS 2
#define LED_FORMAT LED_FORMAT_GRB
#define LEDS_PER_PIXEL 2
#define LEDS_BASE_ANIMATION_INDEX 1
#define LEDS_STATIC_COLOR_INDEX 2
#define LEDS_DPAD_LEFT   0 // 11
#define LEDS_DPAD_DOWN   1//10
#define LEDS_DPAD_RIGHT  2//9
#define LEDS_DPAD_UP     13
#define LEDS_BUTTON_B3   3
#define LEDS_BUTTON_B4   4
#define LEDS_BUTTON_R1   5
#define LEDS_BUTTON_L1   6
#define LEDS_BUTTON_B1   10
#define LEDS_BUTTON_B2   9
#define LEDS_BUTTON_R2   8
#define LEDS_BUTTON_L2   7
#define LEDS_BUTTON_S1   -1
#define LEDS_BUTTON_S2   -1
#define LEDS_BUTTON_L3   12
#define LEDS_BUTTON_R3   11
#define LEDS_BUTTON_A1   14
#define LEDS_BUTTON_A2   15
#define LEDS_BUTTON_A3   -14
#define LEDS_BUTTON_A4   -15
#define HAS_I2C_DISPLAY 1
#define I2C0_ENABLED 1
#define I2C0_PIN_SDA 20
#define I2C0_PIN_SCL 21
#define SPLASH_MODE SPLASH_MODE_STATIC
#define SPLASH_DURATION 2500
#define KEYBOARD_HOST_ENABLED 1
#define DUAL_DIRECTIONAL_ENABLED 1
#define BUTTON_LAYOUT BUTTON_LAYOUT_STICKLESS_16
#define BUTTON_LAYOUT_RIGHT BUTTON_LAYOUT_STICKLESS_16B
#define DEFAULT_SPLASH \
0x00,0x00,0x00,0x00,0x00,0x00,0x00,0x00,0x00,0x00,0x00,0x00,0x00,0x00,0x00,0x00, \
0x00,0x00,0x00,0x00,0x00,0x00,0x00,0x00,0x00,0x00,0x00,0x00,0x00,0x00,0x00,0x00, \
0x00,0x00,0x00,0x00,0x00,0x00,0x00,0x00,0x00,0x00,0x00,0x00,0x00,0x00,0x00,0x00, \
0x00,0x00,0x00,0x00,0x00,0x00,0x00,0x00,0x00,0x00,0x00,0x00,0x00,0x00,0x00,0x00, \
0x00,0x00,0x00,0x00,0x00,0x00,0x00,0x00,0x00,0x00,0x00,0x00,0x00,0x00,0x00,0x00, \
0x00,0x00,0x00,0x00,0x00,0x00,0x00,0x00,0x00,0x00,0x00,0x00,0x00,0x00,0x00,0x00, \
0x00,0x00,0x00,0x00,0x00,0x07,0xFF,0xE0,0x07,0xFF,0xE0,0x00,0x00,0x00,0x00,0x00, \
0x00,0x00,0x00,0x00,0x00,0x1F,0xFF,0xE0,0x07,0xFF,0xF8,0x00,0x00,0x00,0x00,0x00, \
0x00,0x00,0x00,0x00,0x00,0x3F,0xFF,0xE0,0x07,0xFF,0xFC,0x00,0x00,0x00,0x00,0x00, \
0x00,0x00,0x00,0x00,0x00,0x3F,0xFF,0xE7,0xE7,0xFF,0xFC,0x00,0x00,0x00,0x00,0x00, \
0x00,0x00,0x00,0x00,0x00,0x7F,0xFF,0xE7,0xE7,0xFF,0xFE,0x00,0x00,0x00,0x00,0x00, \
0x00,0x00,0x00,0x00,0x00,0x7F,0x00,0x07,0xE0,0x00,0xFE,0x00,0x00,0x00,0x00,0x00, \
0x00,0x00,0x00,0x00,0x00,0x7E,0x00,0x07,0xE0,0x00,0x7E,0x00,0x00,0x00,0x00,0x00, \
0x00,0x00,0x00,0x00,0x00,0x7C,0x7F,0x07,0xE0,0xFE,0x3E,0x00,0x00,0x00,0x00,0x00, \
0x00,0x00,0x00,0x00,0x00,0x7C,0x7F,0x87,0xE0,0xFF,0x3E,0x00,0x00,0x00,0x00,0x00, \
0x00,0x00,0x00,0x00,0x00,0x7C,0xFF,0x87,0xE1,0xFF,0x3E,0x00,0x00,0x00,0x00,0x00, \
0x00,0x00,0x00,0x00,0x00,0x7C,0xFF,0x87,0xE1,0xFF,0x3E,0x00,0x00,0x00,0x00,0x00, \
0x00,0x00,0x00,0x00,0x00,0x7C,0xFF,0x87,0xE1,0xFF,0x3E,0x00,0x00,0x00,0x00,0x00, \
0x00,0x00,0x00,0x00,0x00,0x7C,0xFF,0x87,0xE1,0xFF,0x3E,0x00,0x00,0x00,0x00,0x00, \
0x00,0x00,0x00,0x00,0x00,0x7C,0xFF,0x87,0xE1,0xFF,0x3E,0x00,0x00,0x00,0x00,0x00, \
0x00,0x00,0x00,0x00,0x00,0x7C,0xFF,0x87,0xE1,0xFF,0x3E,0x00,0x00,0x00,0x00,0x00, \
0x00,0x00,0x00,0x00,0x00,0x7C,0xFF,0x87,0xE1,0xFF,0x3E,0x00,0x00,0x00,0x00,0x00, \
0x00,0x00,0x00,0x00,0x00,0x7C,0xFF,0x87,0xE1,0xFF,0x3E,0x00,0x00,0x00,0x00,0x00, \
0x00,0x00,0x00,0x00,0x00,0x7C,0xFF,0x87,0xE1,0xFF,0x3E,0x00,0x00,0x00,0x00,0x00, \
0x00,0x00,0x00,0x00,0x00,0x7C,0xFF,0x87,0xE1,0xFF,0x3E,0x00,0x00,0x00,0x00,0x00, \
0x00,0x00,0x00,0x00,0x00,0x7C,0xFF,0x87,0xE1,0xFF,0x3E,0x00,0x00,0x00,0x00,0x00, \
0x00,0x00,0x00,0x00,0x00,0x7C,0xFF,0x87,0xE1,0xFF,0x3E,0x00,0x00,0x00,0x00,0x00, \
0x00,0x00,0x00,0x00,0x00,0x7C,0xFF,0x87,0xE1,0xFF,0x3E,0x00,0x00,0x00,0x00,0x00, \
0x00,0x00,0x00,0x00,0x00,0x7C,0x7F,0x07,0xE0,0xFF,0x3E,0x00,0x00,0x00,0x00,0x00, \
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

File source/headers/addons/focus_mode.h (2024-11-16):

#ifndef _FocusMode_H
#define _FocusMode_H

#include "gpaddon.h"
#include "gamepad.h"

#ifndef FOCUS_MODE_ENABLED
#define FOCUS_MODE_ENABLED 0
#endif

#ifndef FOCUS_MODE_PIN
#define FOCUS_MODE_PIN -1
#endif

#ifndef FOCUS_MODE_BUTTON_MASK
#define FOCUS_MODE_BUTTON_MASK 0
#endif

#ifndef FOCUS_MODE_OLED_LOCK_ENABLED
#define FOCUS_MODE_OLED_LOCK_ENABLED 0
#endif

#ifndef FOCUS_MODE_RGB_LOCK_ENABLED
#define FOCUS_MODE_RGB_LOCK_ENABLED 0
#endif

#ifndef FOCUS_MODE_BUTTON_LOCK_ENABLED
#define FOCUS_MODE_BUTTON_LOCK_ENABLED 0
#endif

#ifndef FOCUS_MODE_MACRO_LOCK_ENABLED
#define FOCUS_MODE_MACRO_LOCK_ENABLED 1
#endif

// FocusMode Module Name
#define FocusModeName "FocusMode"

class FocusModeAddon : public GPAddon {
public:
	virtual bool available();
	virtual void setup();       // FocusMode Setup
	virtual void process();     // FocusMode Process
	virtual void preprocess() {}
	virtual std::string name() { return FocusModeName; }
	static bool fucus_on_eanble;
	
private:
	uint32_t buttonLockMask;
	uint8_t focusModePin;

};

#endif  // _FocusMode_H_

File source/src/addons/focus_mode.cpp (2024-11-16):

#include "addons/focus_mode.h"
#include "storagemanager.h"
#include "hardware/gpio.h"

bool FocusModeAddon::fucus_on_eanble = false;
bool FocusModeAddon::available() 
{
	const FocusModeOptions &options = Storage::getInstance().getAddonOptions().focusModeOptions;
	return options.enabled &&
		options.buttonLockMask != 0;
		// && isValidPin(options.pin);
}

void FocusModeAddon::setup()
{
	const FocusModeOptions &options = Storage::getInstance().getAddonOptions().focusModeOptions;
	buttonLockMask = options.buttonLockMask;
	focusModePin = options.pin;

	// gpio_init(focusModePin);             // Initialize pin
	// gpio_set_dir(focusModePin, GPIO_IN); // Set as INPUT
	// gpio_pull_up(focusModePin);          // Set as PULLUP
}

void FocusModeAddon::process() 
{
	Gamepad *gamepad = Storage::getInstance().GetGamepad();
	const FocusModeOptions &options = Storage::getInstance().getAddonOptions().focusModeOptions;
	buttonLockMask = options.buttonLockMask;
	if (options.buttonLockEnabled && options.enabled)
	{
			if (buttonLockMask & GAMEPAD_MASK_DU)
			{
				gamepad->state.dpad &= ~GAMEPAD_MASK_UP;
			}
			if (buttonLockMask & GAMEPAD_MASK_DD) 
			{
				gamepad->state.dpad &= ~GAMEPAD_MASK_DOWN;
			}
			if (buttonLockMask & GAMEPAD_MASK_DL) 
			{
				gamepad->state.dpad &= ~GAMEPAD_MASK_LEFT;
			}
			if (buttonLockMask & GAMEPAD_MASK_DR) 
			{
				gamepad->state.dpad &= ~GAMEPAD_MASK_RIGHT;
			}
			gamepad->state.buttons &= ~buttonLockMask;
	}
}

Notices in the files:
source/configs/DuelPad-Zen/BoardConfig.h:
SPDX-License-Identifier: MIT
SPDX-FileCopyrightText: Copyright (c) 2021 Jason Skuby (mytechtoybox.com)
